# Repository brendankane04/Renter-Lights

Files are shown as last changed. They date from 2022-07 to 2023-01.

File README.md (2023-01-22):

# Renter Lights

Automatic light control which doesn't involve messing with your light switches & talking to your landlords

# Firmware 

## Files

**Wifi_Interface.cpp:** Driver to send TCP messages over wifi<br>
**SG90.cpp:** Driver for the SG90 servo, turns it on & off.<br>
**SR501.cpp:** Driver the SR501 PIR sensor. The handler init is can be run independently.<br>
**MQTT.cpp:** Initialization for MQTT events & central event handler.<br>
**pins.h:** definitions of relevant GPIO pins.<br>
**main.cpp:** main file. Combines all the modules.<br>

# Hardware

**Hardware.sch:** The schematics for the minimum unit<br>
**Hardware.kicad_pcb:** The layout file<br>

# Mechanical

# Backend

A mosquitto MQTT broker server on a raspberry pi is used to interface the devicecs. Just get one up & running.

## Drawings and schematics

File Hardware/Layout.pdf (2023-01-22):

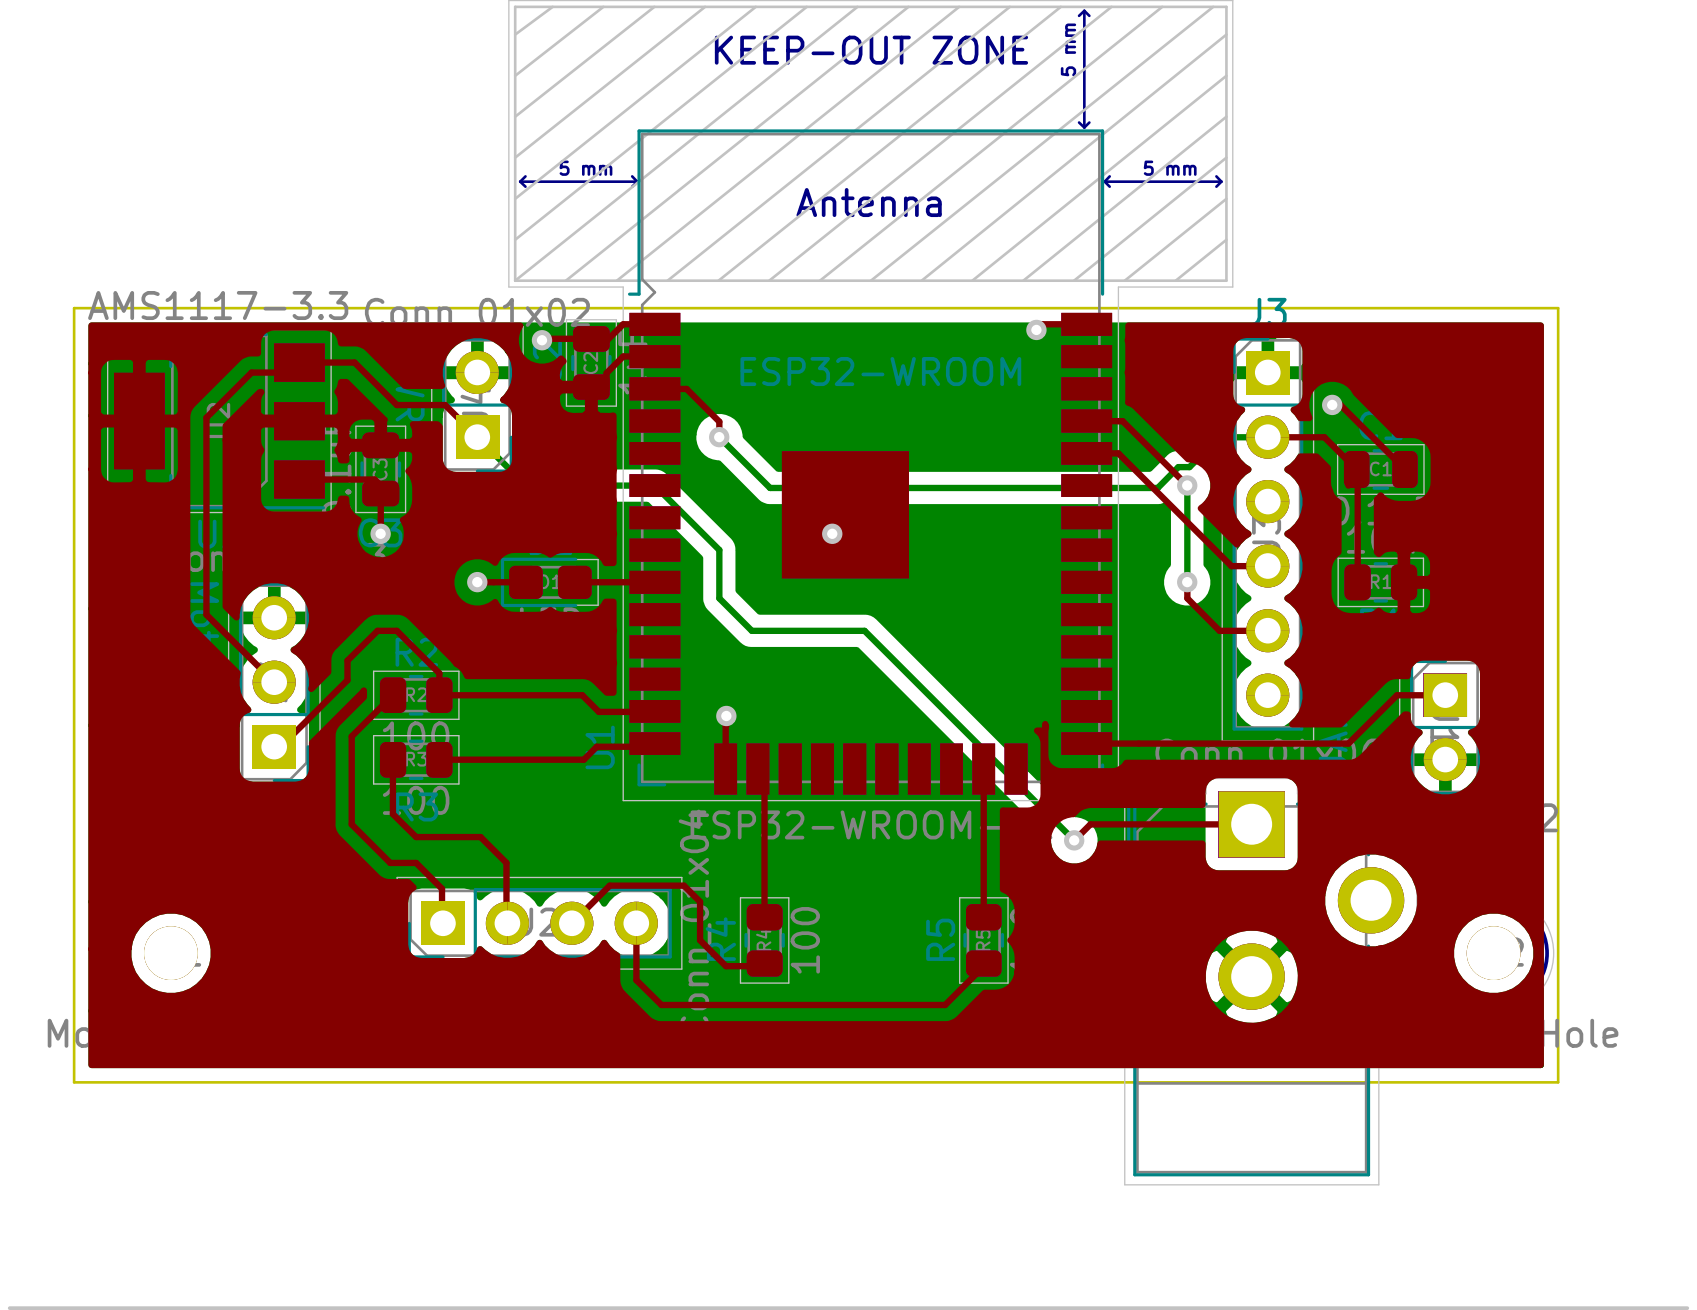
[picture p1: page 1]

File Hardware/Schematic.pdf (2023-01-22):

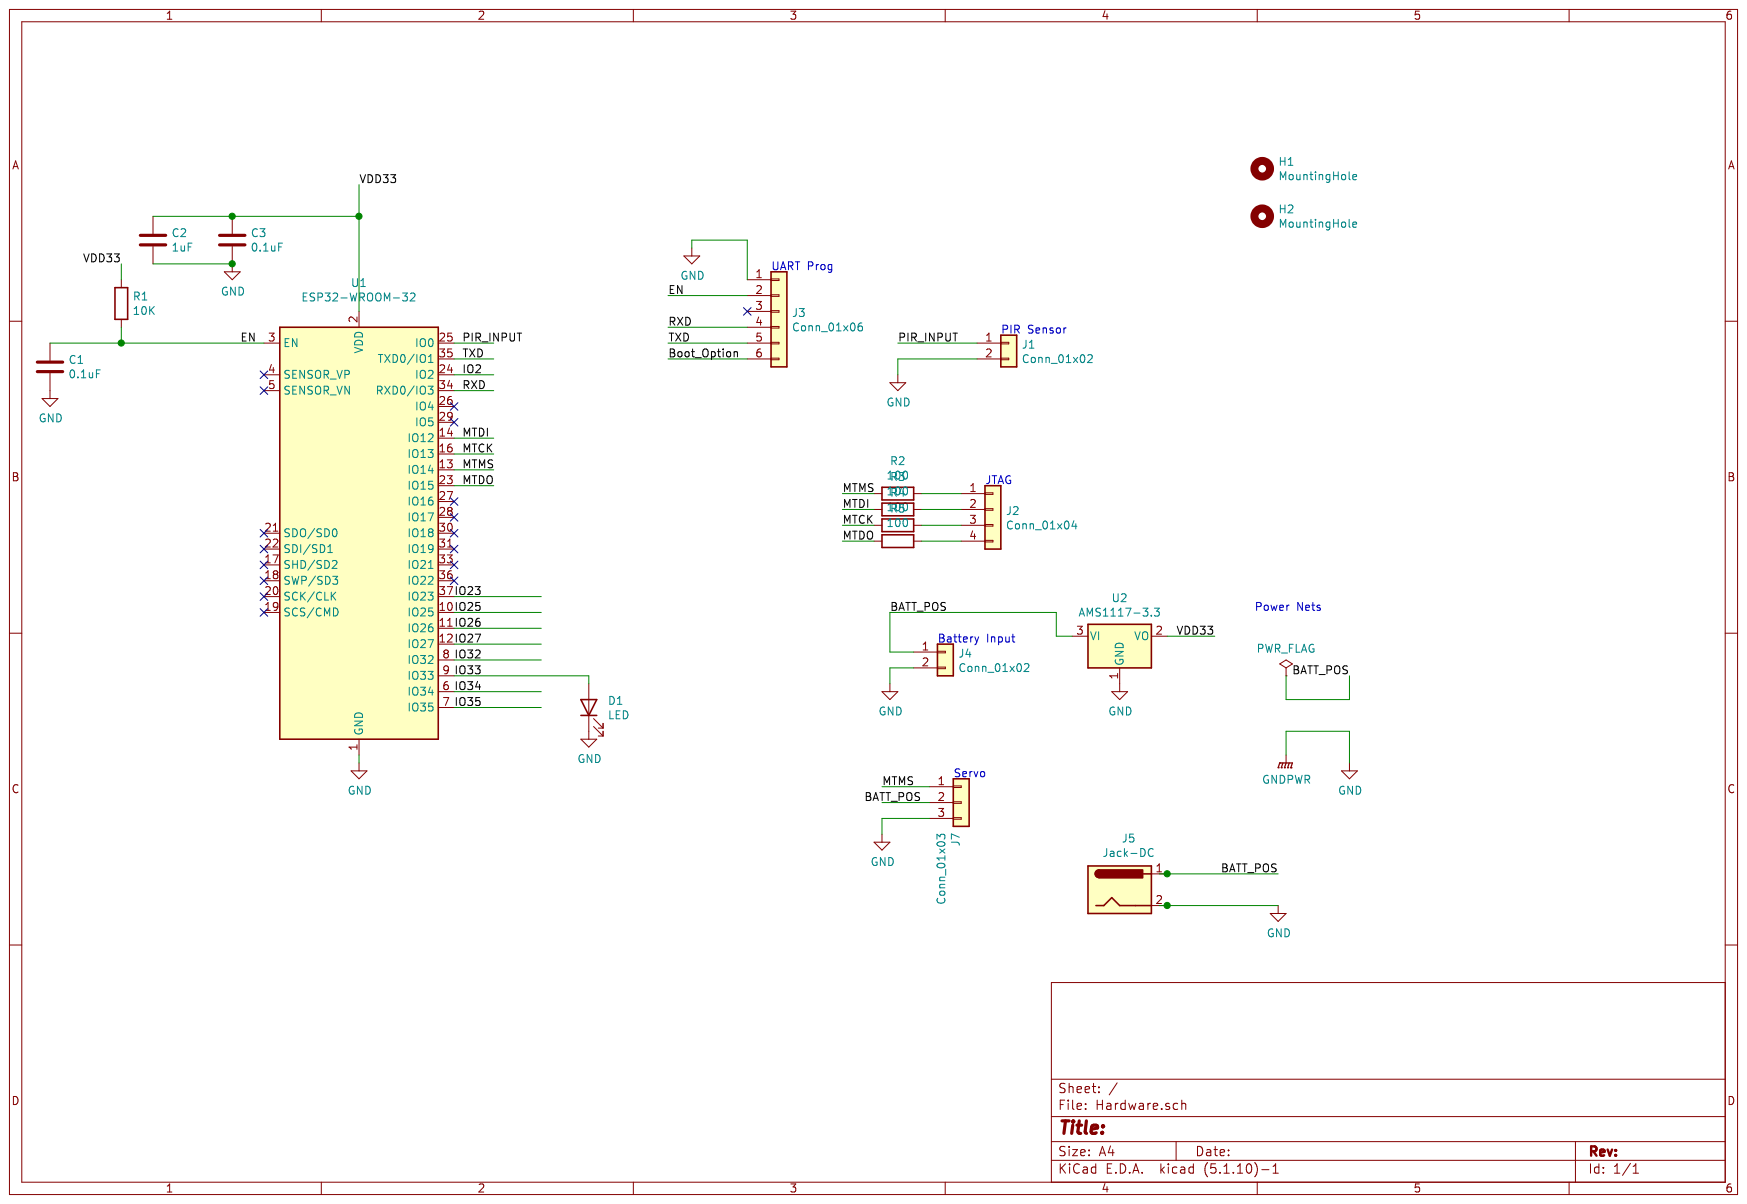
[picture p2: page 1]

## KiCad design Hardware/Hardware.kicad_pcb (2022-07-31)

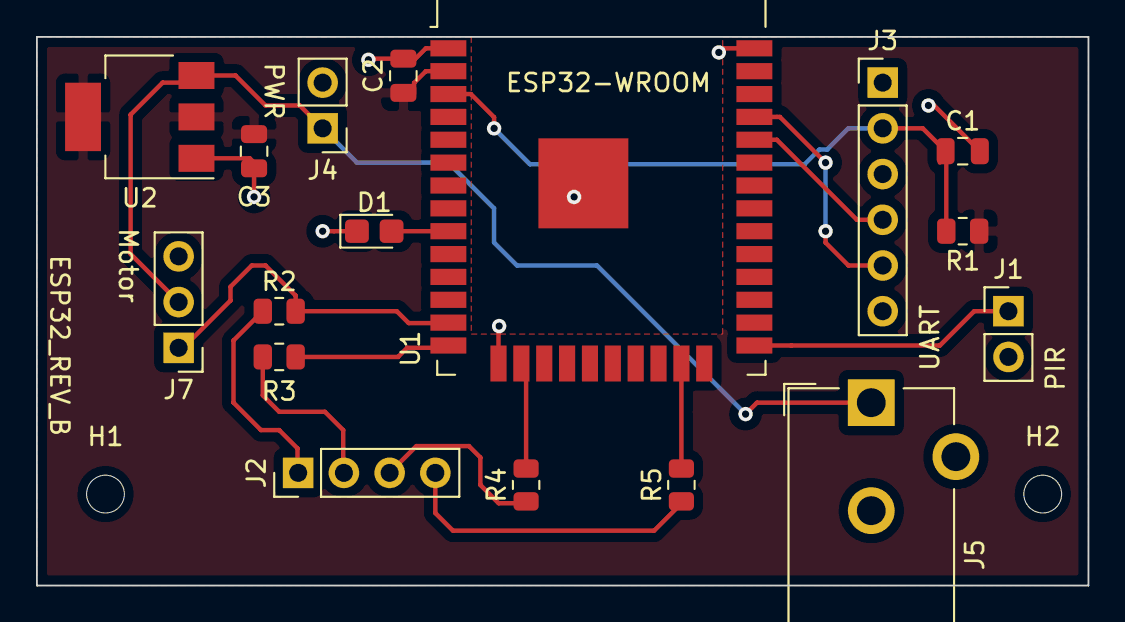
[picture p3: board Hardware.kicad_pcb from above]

Board: 2 copper layers, 58.4 x 30.5 mm, 19 parts (0 on the bottom side), 16 nets.

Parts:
C1, C3: 0.1uF; C_0805_2012Metric
C2: 1uF; C_0805_2012Metric
D1: LED; LED_0805_2012Metric_Castellated
H1, H2: MountingHole; MountingHole_2.1mm
J1, J4: Conn_01x02; PinHeader_1x02_P2.54mm_Vertical
J2: Conn_01x04; PinHeader_1x04_P2.54mm_Vertical
J3: Conn_01x06; PinHeader_1x06_P2.54mm_Vertical
J5: Jack-DC; BarrelJack_CUI_PJ-102AH_Horizontal
J7: Conn_01x03; PinHeader_1x03_P2.54mm_Vertical
R1: 10K; R_0805_2012Metric
R2, R3, R4, R5: 100; R_0805_2012Metric
U1: ESP32-WROOM-32
U2: AMS1117-3.3; SOT-223-3_TabPin2

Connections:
/BATT_POS: J4.1, J5.1, J7.2, U2.3
/EN: C1.1, J3.2, R1.2, U1.3
/IO33: D1.2, U1.9
/MTCK: R4.2, U1.16
/MTDI: R3.2, U1.14
/MTDO: R5.2, U1.23
/MTMS: J7.1, R2.2, U1.13
/PIR_INPUT: J1.1, U1.25
/RXD: J3.4, U1.34
/TXD: J3.5, U1.35
/VDD33: C2.1, C3.1, R1.1, U1.2, U2.2
GND: C1.2, C2.2, C3.2, D1.1, J1.2, J3.1, J4.2, J5.2, J7.3, U1.1, U1.15, U1.38, U1.39, U2.1
unnamed: J2.1, R2.1
unnamed: J2.2, R3.1
unnamed: J2.3, R4.1
unnamed: J2.4, R5.1

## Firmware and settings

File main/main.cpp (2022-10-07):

#include <stdio.h>
#include <string.h>
#include <wifi_interface.h>
#include "freertos/FreeRTOS.h"
#include "freertos/task.h"
#include "esp_attr.h"
#include "driver/gpio.h"
#include "driver/mcpwm.h"
#include "soc/mcpwm_periph.h"
#include "sdkconfig.h"
#include "SG90.h"
#include "SR501.h"
#include "MQTT.h"
#include "pins.h"
#include "esp_sleep.h"

using namespace std;

#define delay(cnt) vTaskDelay(cnt / portTICK_PERIOD_MS)

static const char *TAG = "main";


//Application-specific defines
typedef enum {SERVO_MODE, SENSOR_MODE, BLINK_MODE} operating_mode_t;
#define TARGET_IP "10.0.0.104"
#define TARGET_PORT 21


extern "C" { void app_main(); }

esp_mqtt_client_handle_t static client;
operating_mode_t operating_mode = SERVO_MODE;

//Generic blink
void blink()
{
	gpio_set_level(LED_GPIO, 0);
	delay(1000);
	gpio_set_level(LED_GPIO, 1);
	delay(1000);
}


//Send signals to the network based on the input
//Uncalled by the user, just used by the internals
void populated_signal_handler(void* handler_arg, esp_event_base_t base, int32_t id, void* event_data)
{
    int msg_id;
    wifi.set_target(TARGET_IP, TARGET_PORT);

	switch(id)
	{
		case PIR_EVENT_ENTERED_ROOM:
			ESP_LOGI(TAG, "PIR_ENTERED");
//			wifi.send("PIR_ENTERED\n");
			msg_id = esp_mqtt_client_publish(client, "/topic/test_topic", SERVO_ON, 0, 1, 0);
			ESP_LOGI(TAG, "sent publish successful, msg_id=%d", msg_id);
		break;
		case PIR_EVENT_EXITED_ROOM:
			ESP_LOGI(TAG, "PIR_EXITED");
//			wifi.send("PIR_EXITED\n");
			msg_id = esp_mqtt_client_publish(client, "/topic/test_topic", SERVO_OFF, 0, 1, 0);
			ESP_LOGI(TAG, "sent publish successful, msg_id=%d", msg_id);
		break;
		default:
			ESP_LOGI(TAG, "PIR_UNDEFINED");
//			wifi.send("PIR_UNDEFINED");
			msg_id = esp_mqtt_client_publish(client, "/topic/test_topic", "UNDEFINED", 0, 1, 0);
			ESP_LOGI(TAG, "sent publish successful, msg_id=%d", msg_id);
		break;
	}
}

//Call this function to run the device as a servo
void servo_fn(void *arg)
{
    wifi.set_target(TARGET_IP, TARGET_PORT);
    SG90 servo(TEMP_SIG_GPIO);
    char buffer[9];

	while(1)
	{
		//Read in a string & do a servo command based on it
		memset(buffer, 0x00, 9);
		wifi.recv(buffer, 8);
		ESP_LOGI(TAG, "Received signal (%s)", buffer);
		if(strncmp(buffer, SERVO_ON, 8) == 0)
		{
			servo.set_on();
		}
		else if(strncmp(buffer, SERVO_OFF, 8) == 0)
		{
			servo.set_off();
		}
		else
		{
			ESP_LOGW(TAG, "Unexpected servo signal received %s", buffer);
		}
		delay(100);
	}
}

//Call this function to run the device as a PIR sensor
int sensor_fn(void *arg)
{
    wifi.set_target(TARGET_IP, TARGET_PORT);

    //Start up a new sensor instance & run its internal handler
    SR501 *sensor = new SR501(TEMP_SIG_GPIO, populated_signal_handler);
    return sensor->enable(); //Return the success status of the RTOS call
}

//Call this function to just run a blink
int blink_fn(void *arg)
{
	//Initialize the LED GPIO
	gpio_pad_select_gpio(LED_GPIO);
	gpio_set_direction(LED_GPIO, GPIO_MODE_OUTPUT);
	const int delay = 1000;

	while (1)
	{
		gpio_set_level(LED_GPIO, false);
		delay(delay);
		gpio_set_level(LED_GPIO, true);
		delay(delay);
	}
}

void app_main(void)
{
	//Initialize the LED GPIO
	gpio_pad_select_gpio(LED_GPIO);
	gpio_set_direction(LED_GPIO, GPIO_MODE_OUTPUT);

	//Initialize the wifi
	wifi.init("Home Network", "ThanksBrendan!");
    wifi.set_target(TARGET_IP, TARGET_PORT);

	client = mqtt_init();

//	esp_sleep_enable_ext0_wakeup(PIR_SIG_GPIO,1);
//	esp_sleep_enable_wifi_wakeup();

//	esp_light_sleep_start();

	blink();

	switch(operating_mode)
	{
		case SERVO_MODE:
			servo_fn(NULL);
		break;
		case SENSOR_MODE:
			sensor_fn(NULL);
		break;
		case BLINK_MODE:
			blink_fn(NULL);
		default:
		break;
	}
}

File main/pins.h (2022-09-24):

/*
 * pins.h
 *
 *  Created on: Jul 24, 2022
 *      Author: brend
 */

#ifndef MAIN_PINS_H_
#define MAIN_PINS_H_


//GPIOs currently in use
#define LED_GPIO 		GPIO_NUM_33
#define	PIR_SIG_GPIO 	GPIO_NUM_0
#define	SERVO_SIG_GPIO	GPIO_NUM_14
#define	TEMP_SIG_GPIO	GPIO_NUM_36


#endif /* MAIN_PINS_H_ */

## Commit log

2021-09-01 Stepper motor testing was done.
2021-09-02 Servo control was added.
2021-09-03 The PIR sensor was tested.
2021-09-04 The servo code was simplified.
2021-09-07 Servo code was exported.
2021-09-08 The SG90 driver was cleaned up.
2021-09-08 The SR501 driver was added.
2021-09-13 The wifi driver was developed.
2021-09-13 The wifi driver was completed writing-wise, awaiting testing.
2021-09-15 Errors were removed from the wifi driver.
    [main.cpp]
2021-09-16 A bug in the wifi was fixed.
    [main.cpp]
2021-09-23 A socket init was added.
2021-09-25 Socket dev
2021-09-28 Wifi driver maintenance
2021-09-30 Wifi driver updates
2021-10-03 Driver updates & testing
2021-10-04 The wifi & sensor controls were combined.
2021-10-05 Some sensor changes were started.
2021-10-07 Integration of IR sensor & RTOS
2021-10-09 Sensor updates
2021-10-11 Sensor class changes
2021-11-02 sensor testing
2021-11-04 event was swapped to a function pointer. yayyyyyy......
    [SR501.cpp, main.cpp]
2021-11-07 servo handler started
2021-11-07 servo handler improvement
2021-11-07 more sensor code was removed
2022-02-09 The hardware project was created.
    [Hardware.kicad_pcb, Hardware.sch]
2022-02-12 The schematic was started.
    [Hardware.sch]
2022-02-13 Some hardware dev
    [Hardware.sch]
2022-02-14 Basic hardware bringup for ESP32-WROOM
    [Hardware.sch]
2022-02-15 Hardware dev
    [Hardware.sch]
2022-02-17 Some footprints were fixed.
    [Hardware.sch]
2022-02-17 Routing was done
    [Hardware.kicad_pcb]
2022-02-18 quality of life improvements
    [Hardware.kicad_pcb]
2022-02-20 Motor port addition and ground plane fix
    [Hardware.kicad_pcb, Hardware.sch]
2022-02-21 Silkscreen was added.
    [Hardware.kicad_pcb]
2022-02-21 battery connector update
    [Hardware.kicad_pcb]
2022-02-21 plane updates
    [Hardware.kicad_pcb]
2022-02-22 Code updates
    [Hardware.kicad_pcb]
2022-02-23 Footprint adjustments
    [Hardware.kicad_pcb]
2022-04-10 SMD conversion
    [Hardware.kicad_pcb, Hardware.sch]
2022-04-10 Routings were finished.
    [Hardware.kicad_pcb]
2022-04-14 Added mounting holes
    [Hardware.kicad_pcb, Hardware.sch]
2022-04-15 README update
    [Hardware.kicad_pcb]
2022-04-16 Fill was removed under MCU
    [Hardware.kicad_pcb]
2022-04-17 A board was bought. Yayyyyy!
    [Hardware.kicad_pcb]
2022-04-20 connector fix
    [Hardware.sch]
2022-04-22 A couple heap allocations were removed.
2022-04-22 Programmer fix
    [Hardware.sch]
2022-04-24 layout reworking
    [Hardware.kicad_pcb, Hardware.sch]
2022-04-25 Layout updates
    [Hardware.kicad_pcb]
2022-04-25 Board revision
    [Hardware.kicad_pcb]
2022-04-27 board revising
    [Hardware.kicad_pcb]
2022-05-01 The final board was purchased
    [Hardware.kicad_pcb]
2022-05-06 Filament adjustment
2022-05-07 Filament change
2022-05-20 Removed singleton implementation
    [Hardware.kicad_pcb]
2022-05-20 device testing
2022-05-21 more device testing
2022-05-21 Some servo testing was done
2022-06-21 Implanted servo testing
2022-06-22 Chassis shrinking
2022-07-05 Servo pin fix
    [Hardware-B_Cu.gbl, Hardware-B_Mask.gbs, Hardware-B_Paste.gbp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]
2022-07-11 MQTT & servo testing
2022-07-13 Voltage regulator & power drop testing
    [Hardware.kicad_pcb, Hardware.sch]
2022-07-16 Power supply testing
2022-07-19 Publishes added for the sensor
2022-07-20 Sensor logging & power supply testing
2022-07-22 Power supply fixes
    [Hardware.sch]
2022-07-23 Decoupling cap fix & servo power rewire
    [Hardware.kicad_pcb, Hardware.sch]
2022-07-23 New gerbl created
    [Hardware-B_Cu.gbl, Hardware-B_Mask.gbs, Hardware-B_Paste.gbp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]
2022-07-28 A servo was broken
    [main.cpp]
2022-07-31 Barrel jack was added to board
    [Hardware.kicad_pcb, Hardware.sch]
2022-09-23 New wire placement
2022-09-24 New pin
